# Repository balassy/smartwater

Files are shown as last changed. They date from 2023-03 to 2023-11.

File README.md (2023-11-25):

# SmartWater

SmartWater is a microcontroller-based IoT device to measure water level. It uses an ESP8266 microcontroller and a HC-SR04 ultasonic distance sensor to measure water level then send the measured data to [MagicMirror](https://github.com/MichMich/MagicMirror/).

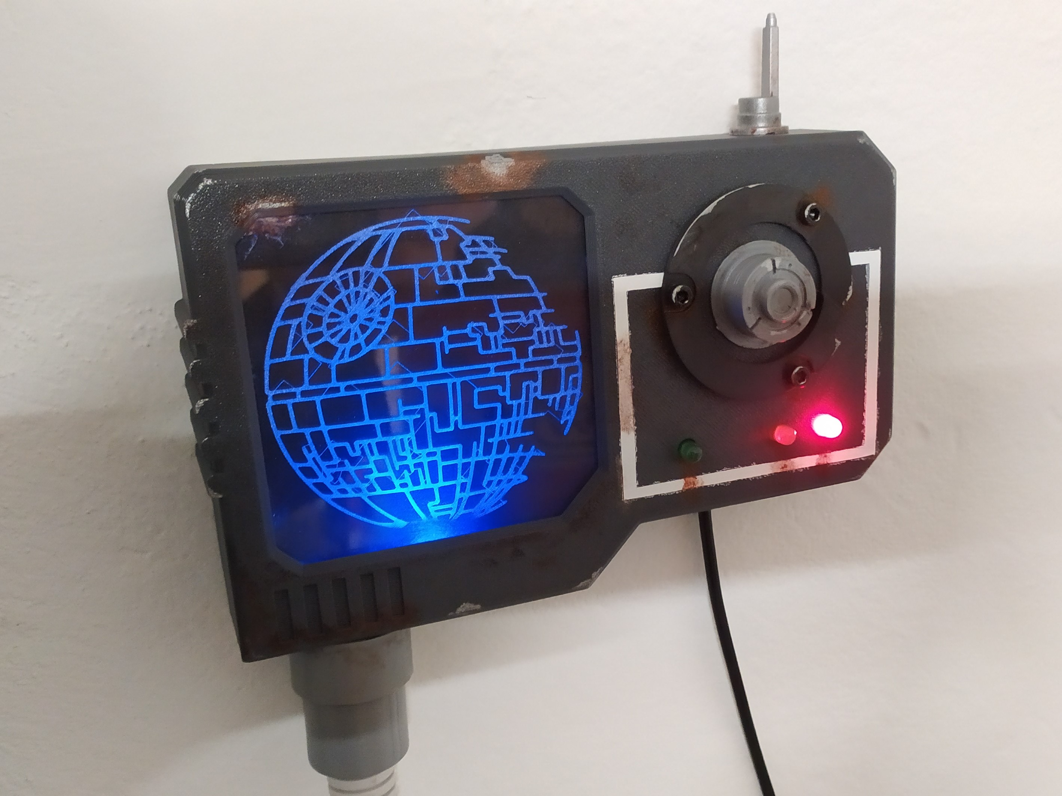
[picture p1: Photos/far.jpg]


## Features

- Measures the water level (distance) in every five (configurable) seconds.
- Averages the values of 3 (configurable) measurements.
- Filters out extreme (configurable) values.
- Sends the measured data to a remote endpoint (e.g. MagicMirror) via HTTP POST (configurable).
- Has an edge lit acrylic panel to indicate that the device is turned on.
- Has 3 LEDs to indicate the water level (green: OK, yellow: warning, red: alert) with configurable thresholds.
- Does a quick LED test when the device is turned on.
- Generic case that can host a 70×50mm prototype PCB.
- Tons of space for greeblies to customize the case.

## Parts

### Bill of Materials

You need the following parts to build this project:

- 1× Wemos D1 Mini microcontroller
- 1× HC-SR04 ultasonic distance sensor
- 1× 70×50 mm prototype PCB 
- 4× LEDs (blue, red, yellow, green)
- 4× 220 Ω resistors
- Pin headers (if you don't want to solder the cable between the display box and the sensor)
- 4-wire cable to connect the sensor to the microcontroller.
- 4× M1 screws to mount the HC-SR04 sensor into the sensor case. You can also use hot glue.
- 4× M2 screws to mount the PCB to the box
- 4× M3 countersunk screws for the back of the display case
- 3× M3 screws for the lid of the sensor case
- 85×85 mm acrylic case
- Glue
- [Greeblies](https://en.wikipedia.org/wiki/Greeble)

### Electronics

Basically:
- Connect the sensor to the microcontroller directly.
- Connect the LEDs to the microcontroller through the resistors.

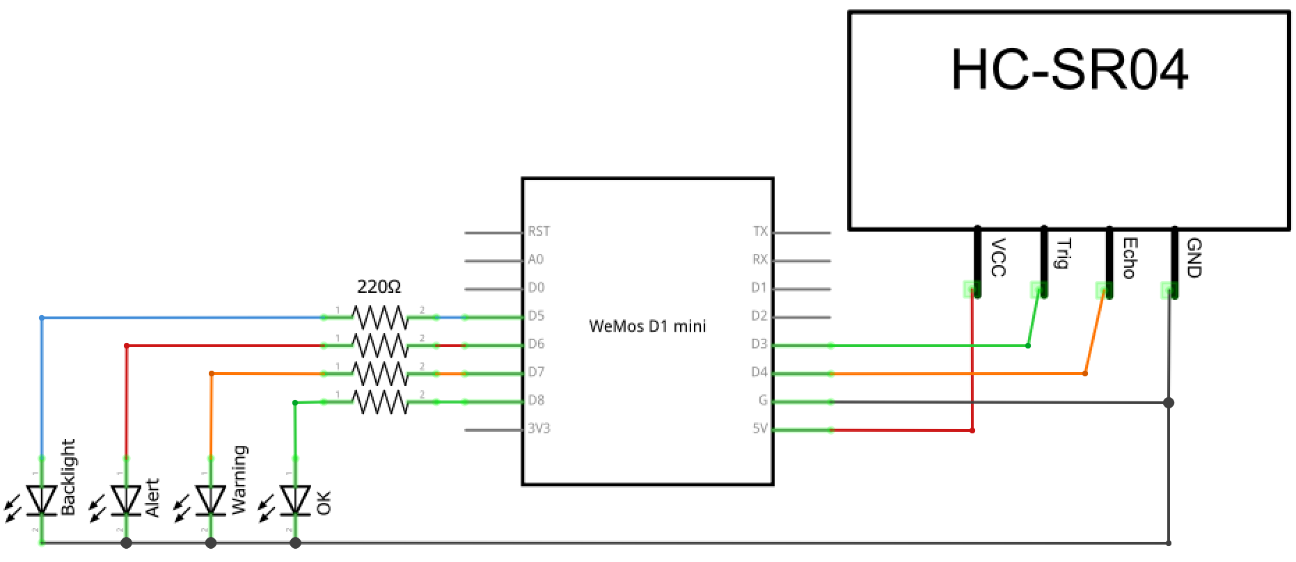
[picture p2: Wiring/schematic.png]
Wiring


### 3D Print

The `3D` folder contains 3D printable files for both the sensor and the display case. No supports needed and you can use 0.3 mm layer height.

I included the original Fusion360 model files, and also exported them to STEP format, so you can modify them to your needs.

I uploaded the [models to Printables](https://www.printables.com/model/417389-sci-fi-project-box) as well, please share your makes there!

### CNC

The case can host a 85×85 mm edge lit acrylic panel. You can carve any drawing to this panel, you can find the source files of the Death Star I used in the `CNC` folder.

### Assembly

1. Assemble the electronics, upload the code, configure and test it.
2. 3D print the cases, CNC carve the acrylic sheet.
3. Mount the PCB inside the display case using M2 screws, and the ultrasonic sensor to the sensor case. Connect them with wires.
4. Glue the acrylic panel into the display case.
5. Glue in the LEDs.
6. Screw the back to the display case and the lid to the sensor case.
7. This is a MUST: Add greeblies and weathering to customize it!

## Software and configuration

You can use the Arduino IDE to open, customize and upload the code in the `SmartWater` folder. The code uses [AutoConnect by Hieromon Ikasamo <hieromon@gmail.com>](https://hieromon.github.io/AutoConnect/index.html) library, so you must install it as a dependency.

The wired pins, threshold levels, measurement parameters, remote endpoint, WiFi SSID and password can be configured at the top of the file. 

You can use the [MMM-SmartWater](https://github.com/balassy/MMM-SmartWater/blob/main/README.md) module to display the measured values in MagicMirror.

## First use

When the device is turned on, it creates a WiFi hotspot, if WiFi connection settings were not configured before. 

**IMPORTANT:** You MUST customize the SSID and password of this temporary WiFi network before uploading the code to your device to prevent malicious usage.

Connect to this WiFi network from your computer or mobile device and let it open the captive portal. The captive portal is served from the microcontroller and will provide a browser based user interface to select your preferred WiFi network and enter your WiFi password.

> In case your browser does not automatically open the settings page navigate to this URL: http://172.217.28.1/_ac

## Improvements ideas

The single blue LED I used for edge lighting the acrylic panel gives an uneven lighting. It brings the used feeling from a galaxy far, far away, still multiple LEDs or a LED strip would highlight the effect more.

## Acknowledgements

Huge thanks to [Octavi Masià](https://grabcad.com/octavi.masia-1) for creating the Fusion360 model of the HC-SR04 ultasonic sensor and made available in the [GrabCad Library](https://grabcad.com/library/ultrasonic-sensor-hc-sr04-1) for the community. It was a great help when I designed the case for the sensor.

Many thanks to [Michael Teeuw](https://github.com/MichMich) for creating and maintaining the [MagicMirror²](https://github.com/MichMich/MagicMirror/) project fully open source.

Many thanks to [Hieromon Ikasamo](https://github.com/Hieromon) for creating and maintaining the [AutoConnect for ESP8266/ESP32](https://hieromon.github.io/AutoConnect/index.html) library. This library and its wonderful documentation was a huge help for implementing the WiFi connection.

## About the author

This project is created and maintained by [György Balássy](https://www.linkedin.com/in/balassy).

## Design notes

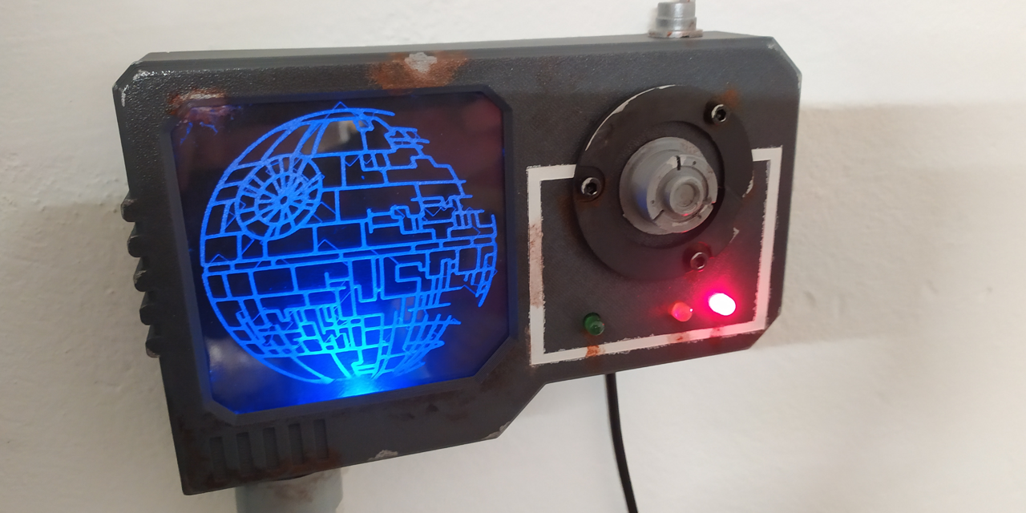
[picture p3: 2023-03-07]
Photos/github-social-preview.png

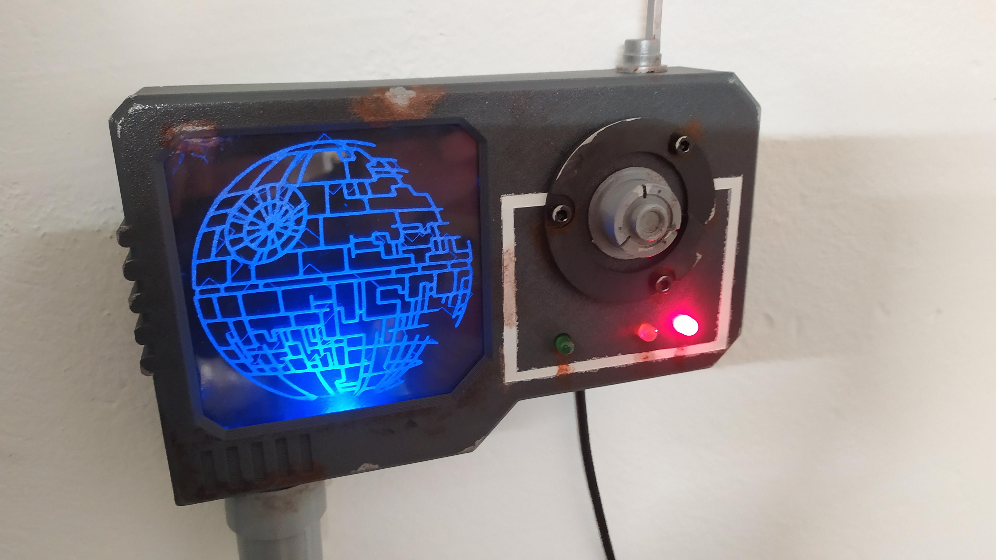
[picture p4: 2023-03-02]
Photos/close.jpg

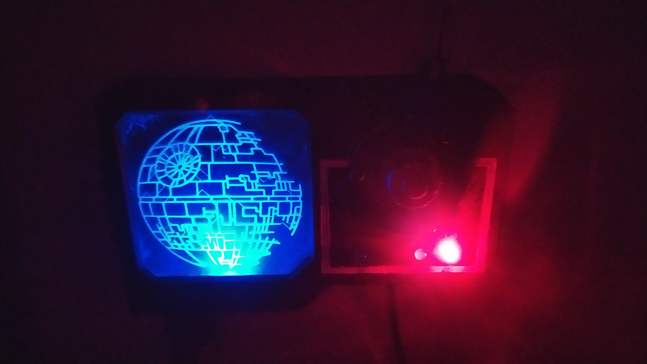
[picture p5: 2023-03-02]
Photos/night.jpg

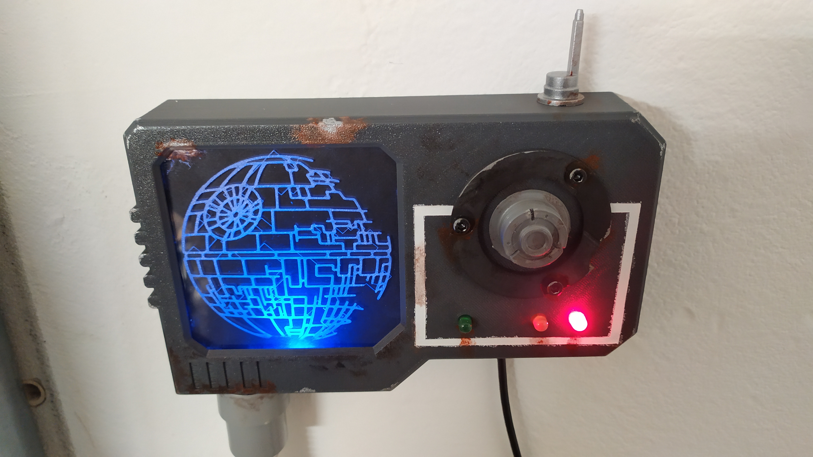
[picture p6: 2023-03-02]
Photos/front.jpg

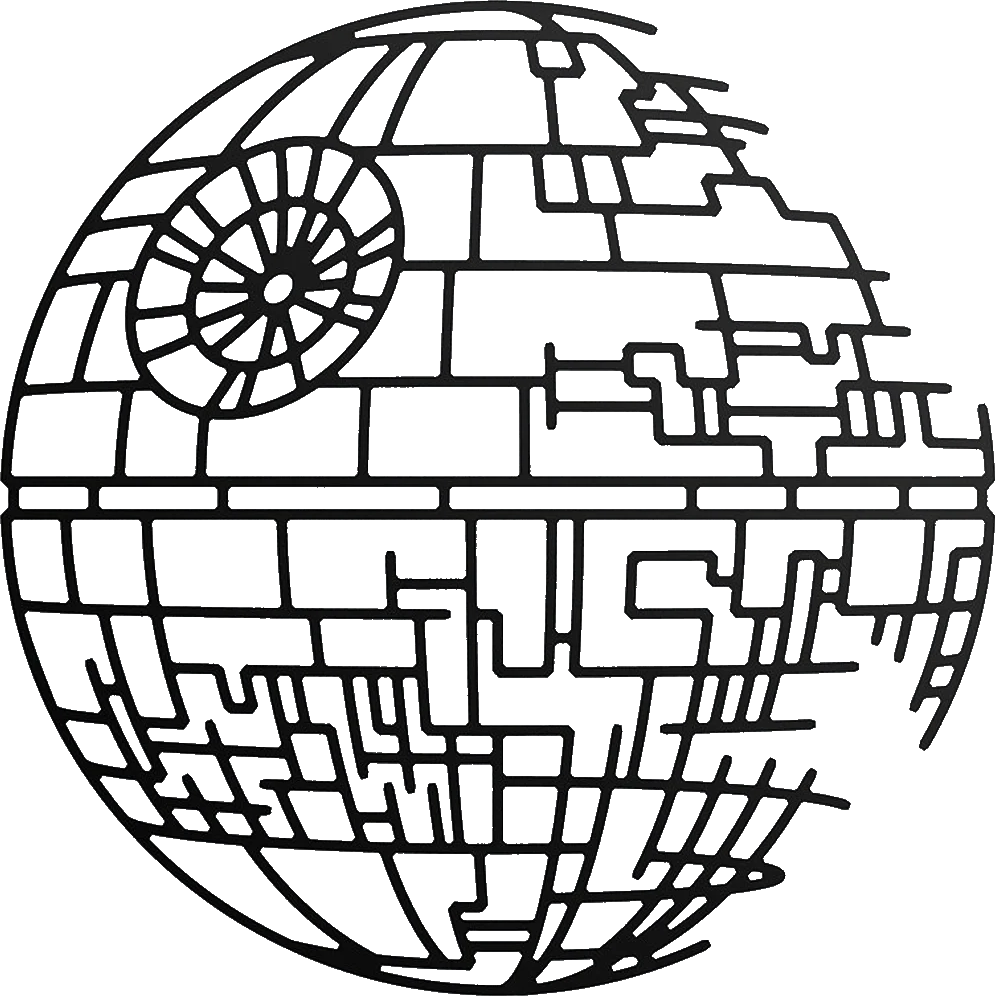
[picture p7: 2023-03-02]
CNC/Death Star.png

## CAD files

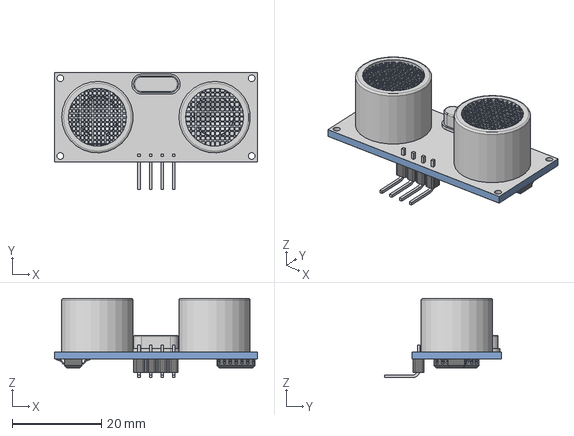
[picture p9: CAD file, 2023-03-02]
3D/HC-SR04 ultrasonic sensor/HC-SR04-UltrasonicSensor v7.step
45.5 x 26.2 x 17.8 mm

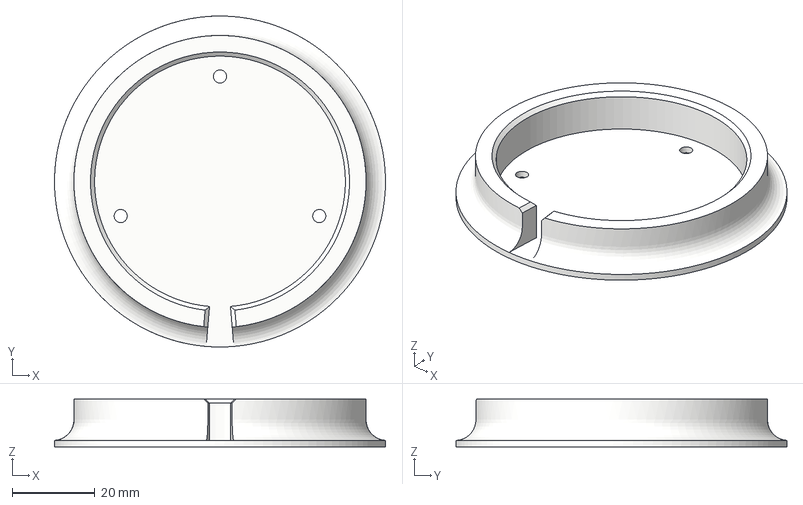
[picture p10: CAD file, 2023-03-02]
3D/Sensor case v11 Lid.3mf
80.0 x 80.0 x 11.6 mm

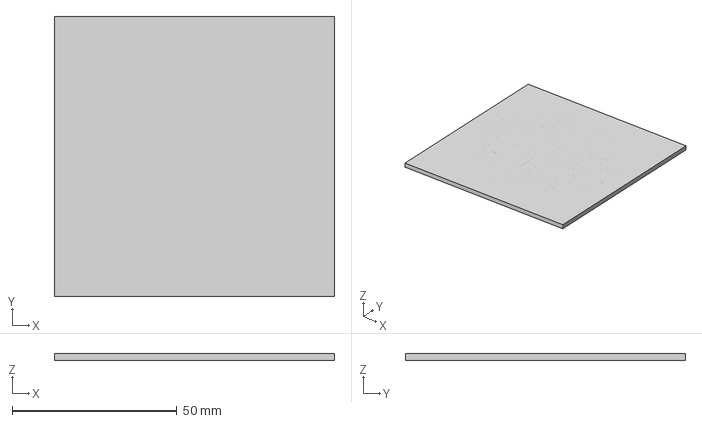
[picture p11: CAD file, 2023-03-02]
CNC/Death Star display v8.3mf
85.0 x 85.0 x 2.00 mm

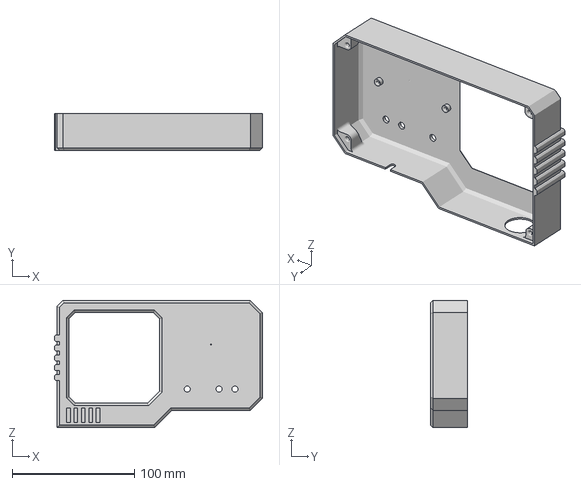
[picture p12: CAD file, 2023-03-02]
3D/Death Star display case v25 Front.3mf
170.0 x 30.0 x 104.0 mm

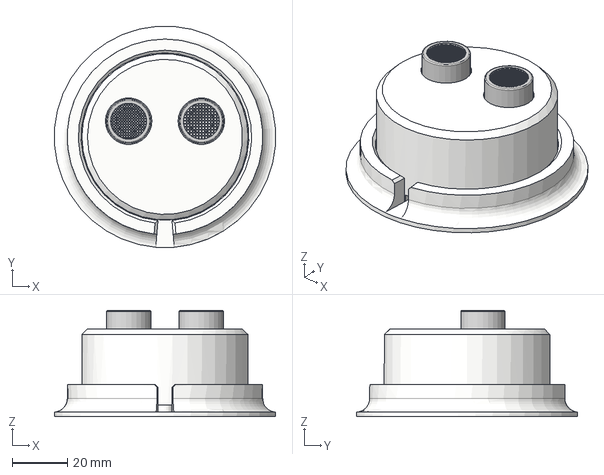
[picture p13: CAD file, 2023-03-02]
3D/Sensor case v11.step
79.8 x 79.9 x 38.3 mm
Lid

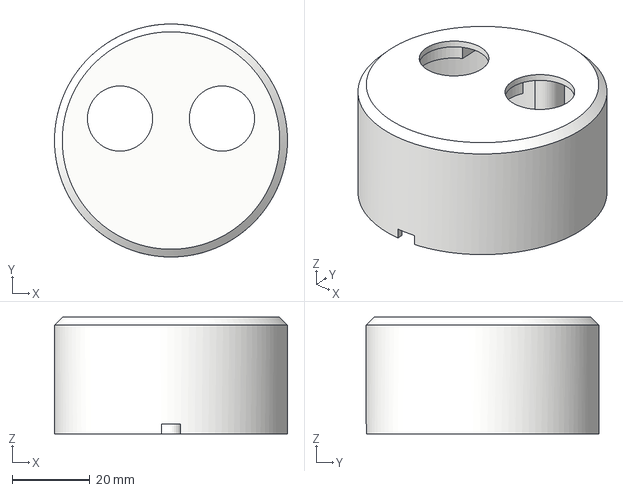
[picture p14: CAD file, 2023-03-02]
3D/Sensor case v11 Box.3mf
60.0 x 60.0 x 30.0 mm

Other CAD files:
3D/Death Star display case v25 Back.3mf
3D/Death Star display case v25.step
3D/Death Star display case v25.f3d
3D/HC-SR04 ultrasonic sensor/HC-SR04-UltrasonicSensor v7.f3d
3D/Sensor case v11.f3d
CNC/Death Star display v8.f3z

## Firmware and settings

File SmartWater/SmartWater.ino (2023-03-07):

#include <ESP8266WiFi.h>
#include <ESP8266WebServer.h>
#include <ESP8266HTTPClient.h>  // To send HTTP requests to MagicMirror.
#include <AutoConnect.h>        // AutoConnect by Hieromon Ikasamo 1.4.2 (https://hieromon.github.io/AutoConnect/index.html)

// Led pins.
int pinWorkingLed = D5;
int pinLevelOkLed = D8;
int pinLevelWarningLed = D7;
int pinLevelAlertLed = D6;

// HC-SR04 ultrasonic sensor pins.
int pinSensorTrigger = D3;
int pinSensorEcho = D4;

// Network.
const char* WIFI_AP_SSID = "SmartWater";             // The name of the wireless network to create if cannot connect using the previously saved credentials.
const char* WIFI_AP_PASSWORD = "SuperSecret";        // The password required to connect to the wireless network used to configure the network parameters.

const char* MAGIC_MIRROR_ENDPOINT = "http://192.168.0.196:8080/smart-water";  // The IP address and port number of the MagicMirror device on the network.

#define UPDATE_INTERVAL_IN_SECONDS 5                // The frequency of measuring data and sending updates in seconds.
#define MEASURE_COUNT 3                             // The number of measurements used for averaging.
#define MIN_OK_DISTANCE_IN_CM 50                    // The minimum value for OK water level. Above this value the green led will turn on.
#define MIN_WARNING_DISTANCE_IN_CM 30               // The minimum value for warning water level. Above this value the yellow led will turn on.
#define MAX_VALID_DISTANCE_IN_CM 200                // The maxmimum value that is accepted as a valid value. Above this the measured values are ignored.

// -------- Config ends --------

#define SOUND_SPEED 0.034 // cm/microSeconds

AutoConnect autoConnect;

enum Level {
  UNKNOWN_LEVEL,
  OK_LEVEL,
  WARNING_LEVEL,
  ALERT_LEVEL
};

void setup() {
  Serial.begin(115200);
  setupLeds();
  setupSensor();
  setupNetwork();
}

void setupLeds() {
  pinMode(pinWorkingLed, OUTPUT);
  pinMode(pinLevelOkLed, OUTPUT);
  pinMode(pinLevelWarningLed, OUTPUT);
  pinMode(pinLevelAlertLed, OUTPUT);

  turnLedOn(pinWorkingLed);
  delay(500);
  turnLedOn(pinLevelOkLed);
  delay(500);
  turnLedOn(pinLevelWarningLed);
  delay(500);
  turnLedOn(pinLevelAlertLed);
  delay(1000);
  turnLedOff(pinLevelOkLed);
  turnLedOff(pinLevelWarningLed);
  turnLedOff(pinLevelAlertLed);  
}

void setupSensor() {
  pinMode(pinSensorTrigger, OUTPUT);
  pinMode(pinSensorEcho, INPUT);
}


void setupNetwork() {
  Serial.println("Connecting to network...");
  
  autoConnect.config(WIFI_AP_SSID, WIFI_AP_PASSWORD);

  if (autoConnect.begin()) {
    Serial.println("WiFi connected: " + WiFi.localIP().toString());
  }
}

void loop() {
  long distanceInCm = measureDistanceInCmAverage();
  if (isValidDistance(distanceInCm)) {
    Serial.println(distanceInCm);
    setLevel(distanceInCm);
    sendToMagicMirror(distanceInCm);

    delay(UPDATE_INTERVAL_IN_SECONDS * 1000);
  }
}

void turnLedOn(int ledPin) {
  digitalWrite(ledPin, HIGH);
}

void turnLedOff(int ledPin) {
  digitalWrite(ledPin, LOW);
}

long measureDistanceInCmAverage() {
  int sum = 0;
  for (int i = 0; i < MEASURE_COUNT; i++) {
    sum += measureDistanceInCmOnce();
    delay(100);
  }
  long averageDistanceInCm = sum / MEASURE_COUNT;
  return averageDistanceInCm;
}

long measureDistanceInCmOnce() {
  // Clear the trigger pin.
  digitalWrite(pinSensorTrigger, LOW);
  delayMicroseconds(2);
  // Send out a 10 micro second signal.
  digitalWrite(pinSensorTrigger, HIGH);
  delayMicroseconds(10);
  digitalWrite(pinSensorTrigger, LOW);
  // Wait for the bounced signal.
  long durationInMicroSeconds = pulseIn(pinSensorEcho, HIGH);
  // Calculate the distance.
  long distanceInCm = durationInMicroSeconds * SOUND_SPEED/2;  
  return distanceInCm;
}

bool isValidDistance(long distanceInCm) {
  return distanceInCm <= MAX_VALID_DISTANCE_IN_CM;
}

void setLevel(long distanceInCm) {
  if (distanceInCm > MIN_OK_DISTANCE_IN_CM) {
    setLevelLeds(OK_LEVEL);
  }
  else if (distanceInCm > MIN_WARNING_DISTANCE_IN_CM) {
    setLevelLeds(WARNING_LEVEL);
  }
  else {
    setLevelLeds(ALERT_LEVEL);
  }
}

void setLevelLeds(Level level) {
  switch (level) {
    case OK_LEVEL:
      turnLedOn(pinLevelOkLed);
      turnLedOff(pinLevelWarningLed);
      turnLedOff(pinLevelAlertLed);  
      break;
    case WARNING_LEVEL:
      turnLedOff(pinLevelOkLed);
      turnLedOn(pinLevelWarningLed);
      turnLedOff(pinLevelAlertLed);      
      break;
    case ALERT_LEVEL:
      turnLedOff(pinLevelOkLed);
      turnLedOff(pinLevelWarningLed);
      turnLedOn(pinLevelAlertLed);       
      break;
    default:
      turnLedOn(pinLevelOkLed);
      turnLedOn(pinLevelWarningLed);
      turnLedOn(pinLevelAlertLed);        
      break;
  }
}

void sendToMagicMirror(long distanceInCm) {
  String requestBody = "{ \"distanceInCm\": " + String(distanceInCm) + " }";
  Serial.println("MagicMirror: HTTP request body: " + requestBody);

  WiFiClient wifiClient;
  HTTPClient http;
  http.begin(wifiClient, MAGIC_MIRROR_ENDPOINT);
  http.addHeader("Content-Type", "application/json");
  
  int statusCode = http.POST(requestBody);

  Serial.printf("MagicMirror: Received HTTP status code: %d\r\n", statusCode);
  if (statusCode != HTTP_CODE_OK) {
    String responseBody = http.getString();
    Serial.println("MagicMirror: Received HTTP response body: " + responseBody);
  }

  http.end();
}

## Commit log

2023-03-02 feat: 3D and CNC files
    [Death Star display case v25 Back.3mf, Death Star display case v25 Front.3mf, Death Star display case v25.f3d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]
2023-03-07 fix: pin layout
2023-03-07 doc: wiring
    [SmartWater.fzz]
2023-03-07 doc: Printables link
